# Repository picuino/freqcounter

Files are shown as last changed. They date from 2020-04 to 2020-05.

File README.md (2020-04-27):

Frequency counter
=================
This is a cheap and simple but powerful frequency counter capable 
of measurements of frequency with 8 digits of resolution every second
(9 digits of resolution in 10 second averages).

This frequency counter is based on a little **PIC 16F18446** a 
16x2 LCD display (optional) and USB-Serial interface with PC.

All the programs and hardware designs are free, open source and
open hardware.

The frequency counter have a Command Line Interface via serial 
communications for manage multiple internal options. 
You can read more in [Command Line Interface help](docs/commands.md)

You can mount the frequency counter over a breadboard with this simple 
[schematic](breadboard/kicad/freqcounter_16F18446.pdf)
with a cost of few dollars.
The LDC display is optional. All the info is sended via serial.

Specifications
--------------
* Input frequency range: 0.01 Hz to 15MHz
* Resolution: 8 digits per second (10ns of resolution) at all frequencies.
* Precision: 0.1PPM with simple crystal and calibration.
* Number of inputs: 2 TTL inputs + 1 Zero Cross Detection input
* Output: Frequency or Period, time and pulses counted.
* Phase delay: between 2 inputs with 10ns of resolution.
* Gate times: 1 second and 0.1 seconds.
* Output: via LCD (optional) and serial UART.
* Autocalibration: with 1PPS signal or with 10MHz signal.
* Reciprocal counting: allow calculate lower frequencies with decimals.
* Continuous timestamp: allow frequency averages without error.
* Frequency autorange from Mega Hertz to milli Hertz.
* Adaptable system frequency without reprogramming (8MHz internal or 5MHz external)
* Command Line Interface: via USB-serial communications for configuring options.
* Input levels: between 0.8v (LOW) and 3.1V (HIGH).
* Power Supply: 5 volts.
* DIY: you can mount it with a breadboard and one crystal oscillator.

Images
------
Example of frequency meter conected to an Arduino.
Arduino gives power and serial communications with PC.

Orange cables are the 2 TTL inputs.

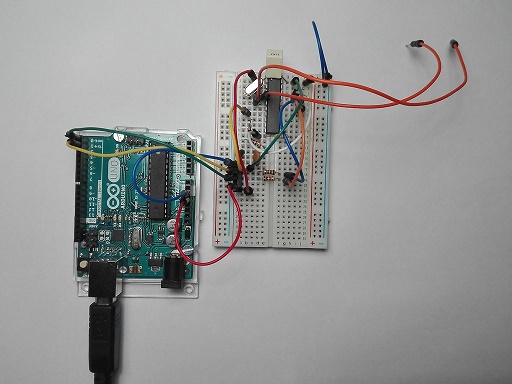
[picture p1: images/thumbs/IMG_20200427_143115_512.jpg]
Frequency meter on breadboard with Arduino


[Full image](images/IMG_20200427_143115.jpg)

Licenses
--------

* Creative Commons Atribution-ShareAlike version 4, for hardware designs,
  texts, photograps, layouts, schematics, and similar.

* GNU General Public License version 3, for microcontroller 
  and computer programs.

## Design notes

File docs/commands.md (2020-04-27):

Frequency counter Command Line Interface
========================================
Brief description of the serial commands that accepts the frequency counter.

The frequency counter communicates with PC via serial.
A USB-Serial converter is needed in order to make serial communications.

The configuration of serial interface is standard:
  * 1 initial start bit
  * 8 data bits
  * 1 stop bit at the end
  * 115200 bauds

Every command line must be terminated with new line character ('\n' or 0x0A).
Other characters like carriage return ('\r' or 0x0D) will be ignored.

Outputs
-------

<dl>

<dt>output time on</dt>
<dd>Enable printing of the duration of the sampling period.</dd>

<dt>output time off</dt>
<dd>Disable printing of the duration of the sampling period.</dd>

<dt>output pulses on</dt>
<dd>Enable printing of counted pulses during the sampling period.</dd>

<dt>output pulses off</dt>
<dd>Disable printing of counted pulses during the sampling period.</dd>

<dt>output longfreq on</dt>
<dd>Enable printing of average frequency of last 10 readings 
    with one digit of resolution added.</dd>

<dt>output longfreq off</dt>
<dd>Disable printing of average frequency.</dd>

<dt>output period on</dt>
<dd>Enable printing of period instead of frequency.</dd>

<dt>output period off</dt>
<dd>Disable printing of frequency instead of period.</dd>

<dt>output phase on</dt>
<dd>Enable printing of time phase between 2 inputs. 
    A minimal phase of 110us is needed between the inputs.</dd>

<dt>output phase off</dt>
<dd>Disable printing of phase between 2 inputs.</dd>

</dl>

Inputs
------

<dl>

<dt>input ch A</dt>
<dd>Activate frequency measure in channel A and switch off channel B.</dd>

<dt>input ch B</dt>
<dd>Activate frequency measure in channel B and switch off channel A.</dd>

<dt>input ch AB</dt>
<dd>Activate frequency measure in both channel A and channel B.</dd>

<dt>input ch</dt>
<dd>Return actual active channels.</dd>

<dt>input ctmu on</dt>
<dd>Enable measurement of frequency with one digit more resolution.
    The measurement is developed with the charge of capacitor 
    (Charge Time Measurement Unit).</dd>

<dt>input ctmu off</dt>
<dd>Disable measurement of frequency with CTMU.</dd>

<dt>input ctmu</dt>
<dd>Return the actual value of ctmu measurement.</dd>

<dt>input fast on</dt>
<dd>Enable fast measurement of frequency (gate time of 0.1 second).</dd>

<dt>input fast off</dt>
<dd>Disable fast measurement of frequency (gate time of 1.0 second).</dd>

<dt>input fast</dt>
<dd>Return the actual value of fast measurement.</dd>

<dt>input zcd on</dt>
<dd>Enable ZCD input instead of Input A.
    The ZCD (Zero Cross Detect) input detects zero crossing of 
    sinusoidal signals like pure audio tones.</dd>

<dt>input zcd off</dt>
<dd>Disable the ZCD input and connect the Input A.</dd>

Calibration
-----------

<dl>

<dt>cal read</dt>
<dd>Read calibration value in PPB (Parts Per Billion).
  Show the calibration value in RAM (value currently used)
  and the calibration value in EPROM (value used after power on).
</dd>

<dt>cal write [number]</dt>
<dd>Writes a new calibration value to calibration variable.</dd>

<dt>cal save</dt>
<dd>Save the actual value of calibration in Flash memory, so this 
  value will be readed after next reset or power on.</dd>

<dt>cal auto on</dt>
<dd>Switch on the autocalibration mode. 
  In this mode the frequency counter changes the calibration value 
  so that the reading is exactly 1Hz or 10MHz.
  
  The frequency counter detects automatically the frequency measured
  and only responds to frequencies near 1Hz or near 10MHz.
  This calibration value in maintained in RAM memory. If you want
  to make this value fixed, use the "cal save" command</dd>

<dt>cal auto off</dt>
<dd>switch off autocalibration mode.</dd>

<dt>cal auto</dt>
<dd>Return the actual value of autocalibration mode.</dd>

</dl>

Reset
-----
<dl>
<dt>reset</dt>
<dd>Reset frequency counter options and counters.</dd>
</dl>

Version
-------
<dl>
<dt>version</dt>
<dd>Shows the version date of the firmware.</dd>
</dl>

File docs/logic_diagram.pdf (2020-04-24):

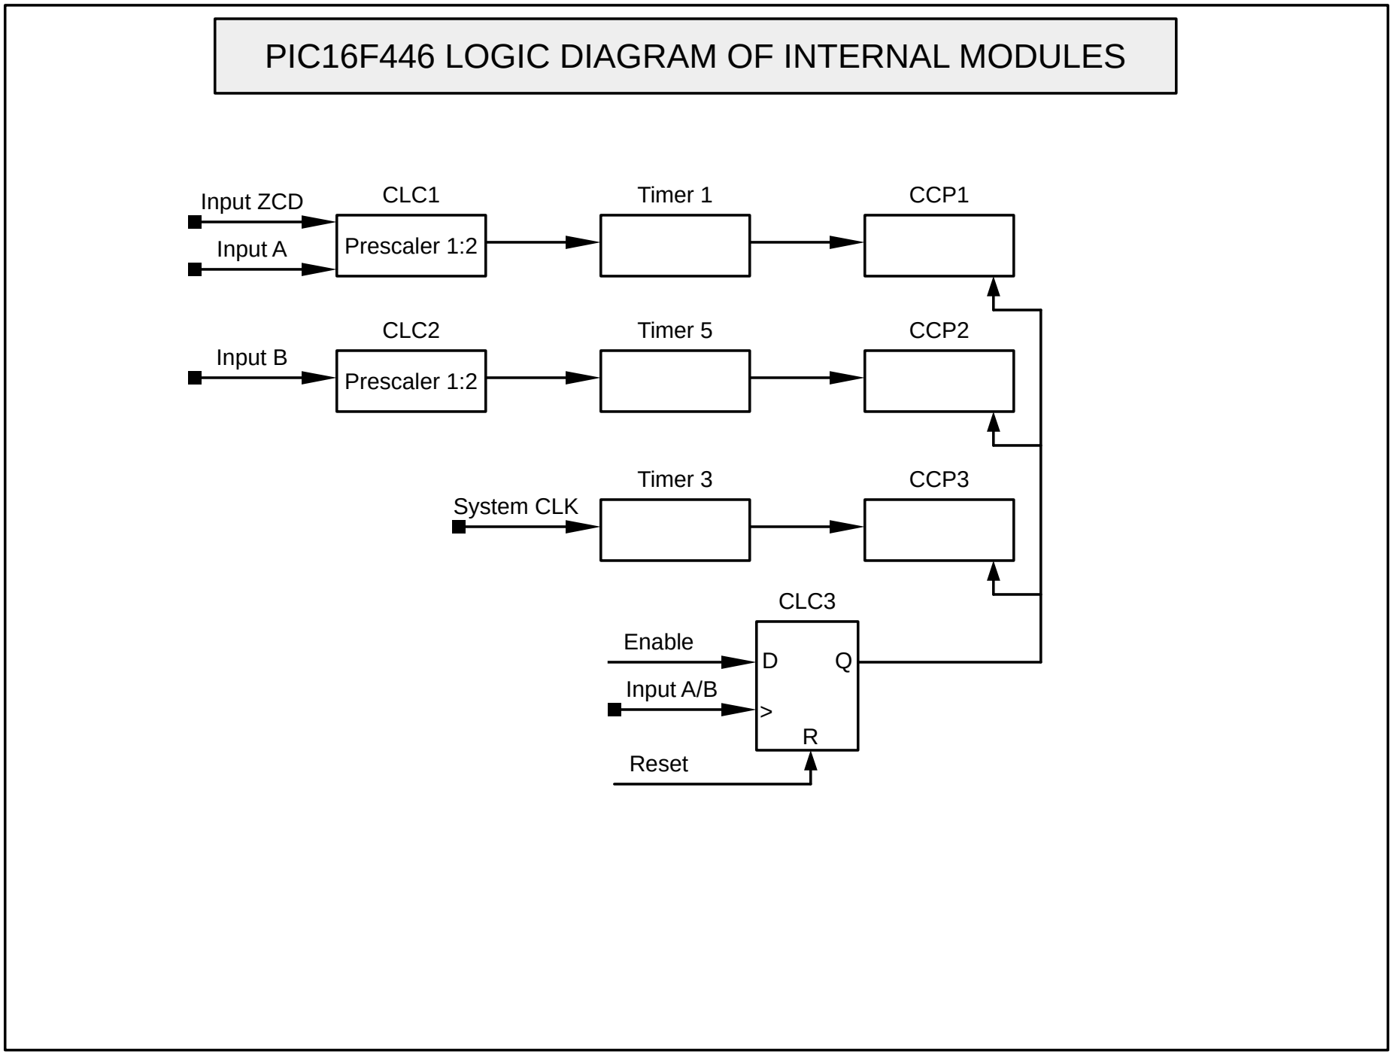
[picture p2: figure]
Prescaler 1:2; CLC1; Input A; Timer 1; CLC2; Input B; Timer 5; System CLK; Timer 3; CCP2; CCP1; CCP3; CLC3; Input A/B; Enable; Reset; Input ZCD

## PIC16F446 LOGIC DIAGRAM OF INTERNAL MODULES

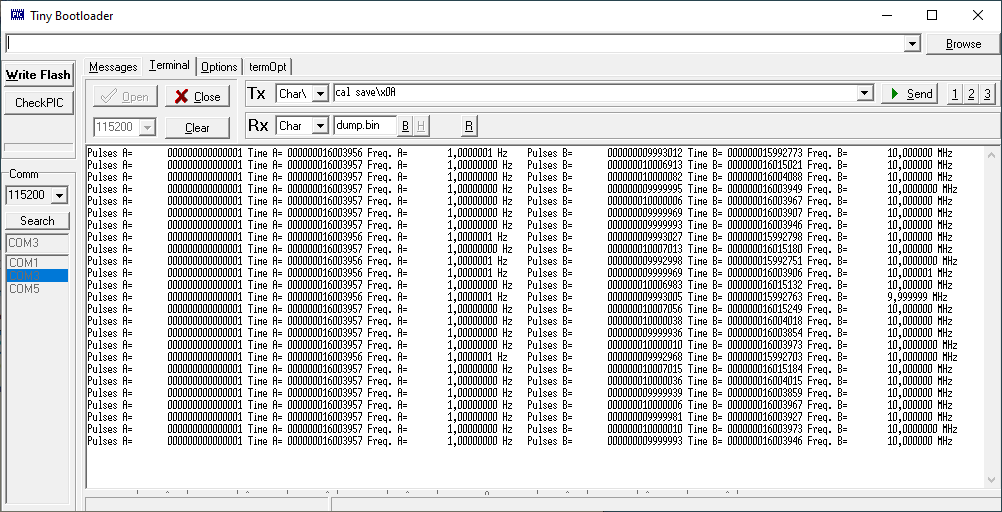
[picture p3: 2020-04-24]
images/two_inputs_GPS_OCXO_0001.png

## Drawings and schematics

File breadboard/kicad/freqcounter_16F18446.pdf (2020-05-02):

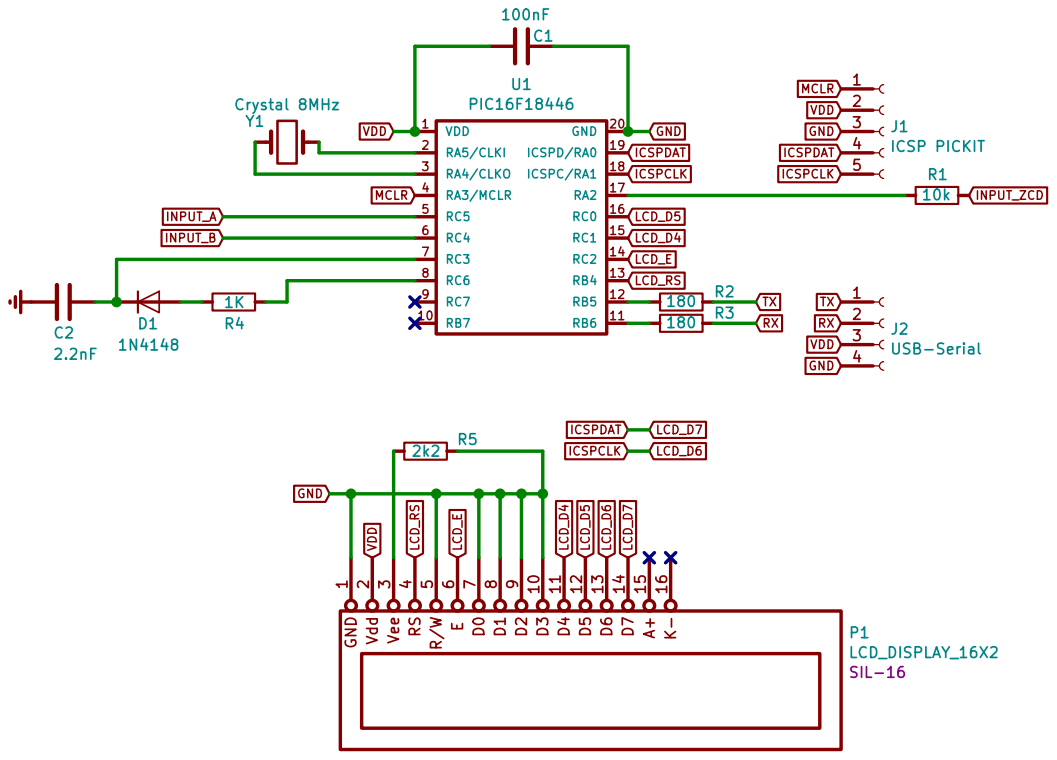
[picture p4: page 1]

License CC BY-SA 4.0
File: freqcounter_16F18446.sch Sheet: / PICUINO

Id: 1/1 Title: FREQUENCY COUNTER WITH PIC16F18446

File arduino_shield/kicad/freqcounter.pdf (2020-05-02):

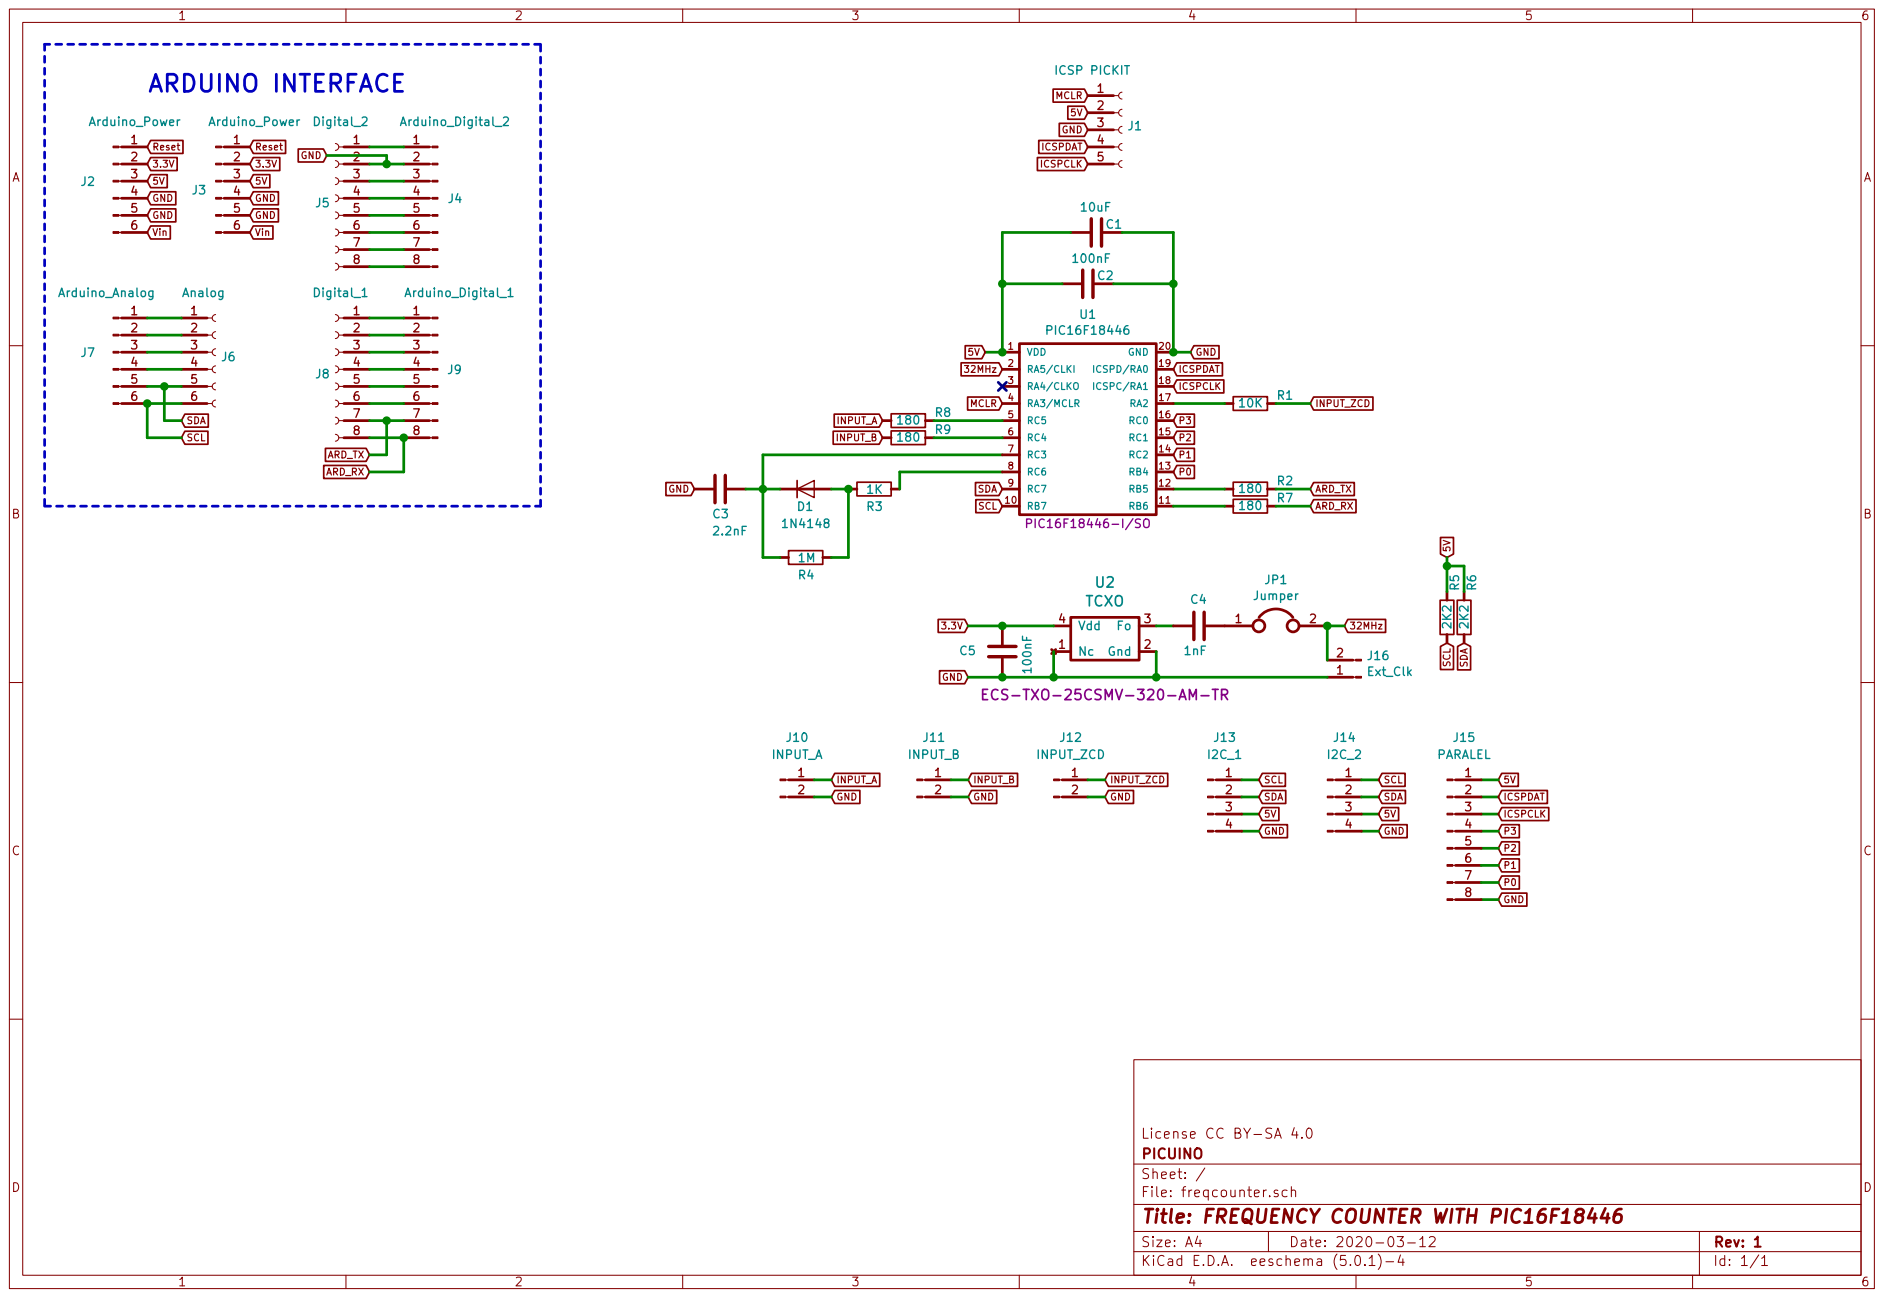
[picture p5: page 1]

ECS-TXO-25CSMV-320-AM-TR

License CC BY-SA 4.0
File: freqcounter.sch Sheet: / PICUINO

Id: 1/1 Title: FREQUENCY COUNTER WITH PIC16F18446

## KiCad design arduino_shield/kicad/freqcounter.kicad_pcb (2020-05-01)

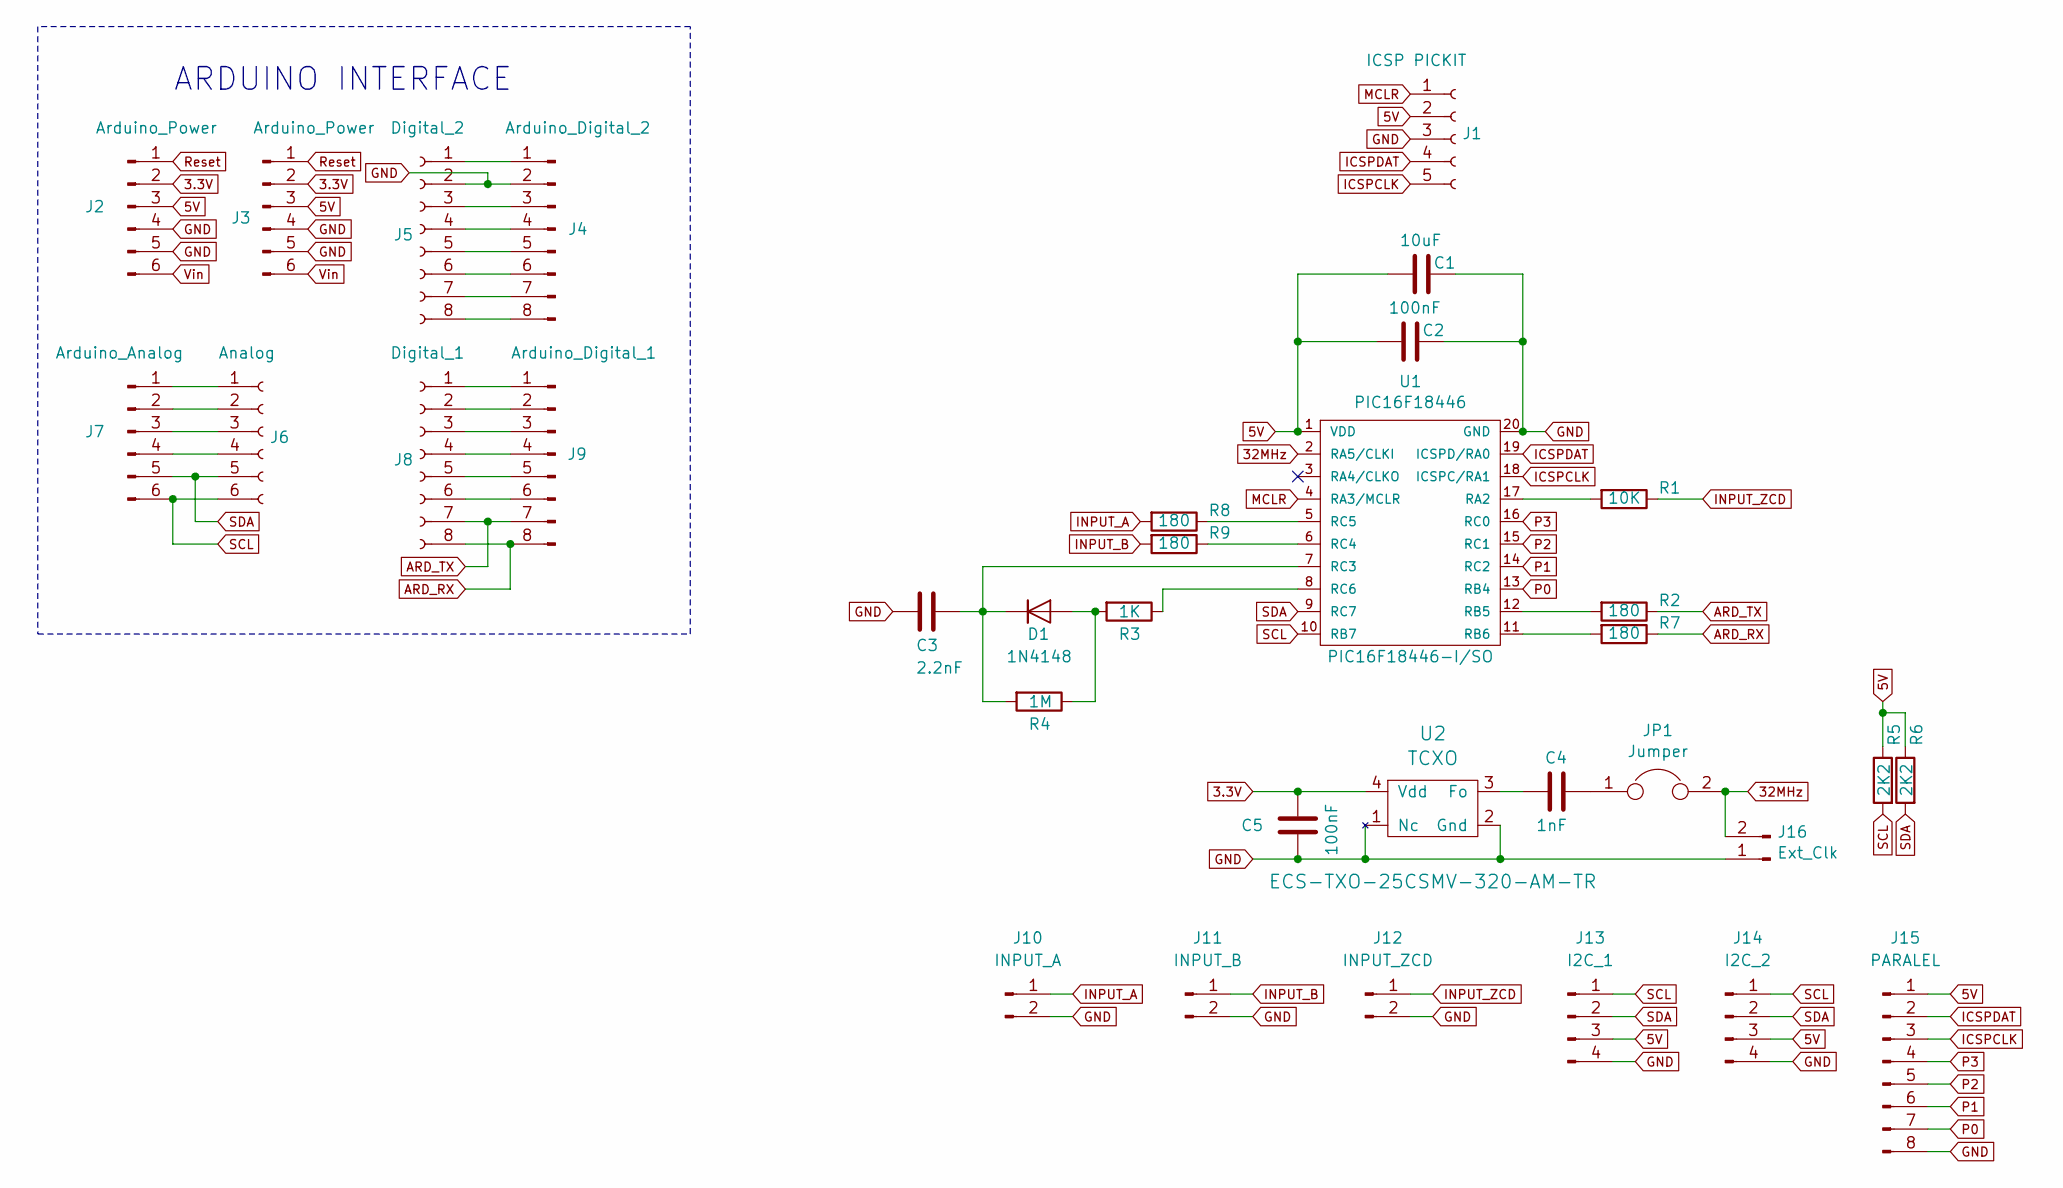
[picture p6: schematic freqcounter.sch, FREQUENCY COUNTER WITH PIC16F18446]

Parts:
C1: 10uF; C_0805_2012Metric_Pad1.15x1.40mm_HandSolder
C2, C5: 100nF; C_0805_2012Metric_Pad1.15x1.40mm_HandSolder
C3: 2.2nF; C_0805_2012Metric_Pad1.15x1.40mm_HandSolder
C4: 1nF; C_0805_2012Metric_Pad1.15x1.40mm_HandSolder
D1: 1N4148; SOD-80_HandSolder
J1: ICSP PICKIT; PinHeader_1x05_P2.54mm_Vertical
J2, J3: Arduino_Power; Connector_1x06
J4: Arduino_Digital_2; Connector_1x08
J5: Digital_2; Connector_1x08
J6: Analog; Connector_1x06
J7: Arduino_Analog; Connector_1x06
J8: Digital_1; Connector_1x08
J9: Arduino_Digital_1; Connector_1x08
J10: INPUT_A; PinHeader_1x02_P2.54mm_Vertical
J11: INPUT_B; PinHeader_1x02_P2.54mm_Vertical
J12: INPUT_ZCD; PinHeader_1x02_P2.54mm_Vertical
J13: I2C_1; PinHeader_1x04_P2.54mm_Vertical
J14: I2C_2; PinHeader_1x04_P2.54mm_Vertical
J15: PARALEL; Connector_1x08
J16: Ext_Clk; PinHeader_1x02
JP1: Jumper; PinHeader_1x02
R1: 10K; R_0805_2012Metric_Pad1.15x1.40mm_HandSolder
R2, R7, R8, R9: 180; R_0805_2012Metric_Pad1.15x1.40mm_HandSolder
R3: 1K; R_0805_2012Metric_Pad1.15x1.40mm_HandSolder
R4: 1M; R_0805_2012Metric_Pad1.15x1.40mm_HandSolder
R5, R6: 2K2; R_0805_2012Metric_Pad1.15x1.40mm_HandSolder
U1: PIC16F18446; SOIC-20W_7.5x12.8mm_P1.27mm
U2: TCXO; TCXO-5032

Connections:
3.3V: C5.2, J2.2, J3.2, U2.4 (Vdd)
5V: C1.2, C2.2, J1.2, J2.3, J3.3, J13.3, J14.3, J15.1, R5.1, R6.1, U1.1 (VDD)
32MHz: J16.2, JP1.2, U1.2 (RA5/CLKI)
ARD_RX: J8.8, J9.8, R7.1
ARD_TX: J8.7, J9.7, R2.1
GND: C1.1, C2.1, C3.2, C5.1, J1.3, J2.4, J2.5, J3.4, J3.5, J4.2, J5.2, J10.2, J11.2, J12.2, J13.4, J14.4, J15.8, J16.1, U1.20 (GND), U2.1 (Nc), U2.2 (Gnd)
ICSPCLK: J1.5, J15.3, U1.18 (ICSPC/RA1)
ICSPDAT: J1.4, J15.2, U1.19 (ICSPD/RA0)
INPUT_A: J10.1, R8.2
INPUT_B: J11.1, R9.2
INPUT_ZCD: J12.1, R1.1
MCLR: J1.1, U1.4 (RA3/MCLR)
unnamed: C3.1, D1.1 (K), R4.2, U1.7 (RC3)
unnamed: C4.1, U2.3 (Fo)
unnamed: C4.2, JP1.1
unnamed: D1.2 (A), R3.2, R4.1
unnamed: J4.1, J5.1
unnamed: J4.3, J5.3
unnamed: J4.4, J5.4
unnamed: J4.5, J5.5
unnamed: J4.6, J5.6
unnamed: J4.7, J5.7
unnamed: J4.8, J5.8
unnamed: J6.1, J7.1
unnamed: J6.2, J7.2
unnamed: J6.3, J7.3
unnamed: J6.4, J7.4
unnamed: J8.1, J9.1
unnamed: J8.2, J9.2
unnamed: J8.3, J9.3
unnamed: J8.4, J9.4
unnamed: J8.5, J9.5
unnamed: J8.6, J9.6
unnamed: R1.2, U1.17 (RA2)
unnamed: R2.2, U1.12 (RB5)
unnamed: R3.1, U1.8 (RC6)
unnamed: R7.2, U1.11 (RB6)
unnamed: R8.1, U1.5 (RC5)
unnamed: R9.1, U1.6 (RC4)
P0: J15.7, U1.13 (RB4)
P1: J15.6, U1.14 (RC2)
P2: J15.5, U1.15 (RC1)
P3: J15.4, U1.16 (RC0)
Reset: J2.1, J3.1
SCL: J6.6, J7.6, J13.1, J14.1, R5.2, U1.10 (RB7)
SDA: J6.5, J7.5, J13.2, J14.2, R6.2, U1.9 (RC7)
Vin: J2.6, J3.6

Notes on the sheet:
ARDUINO INTERFACE

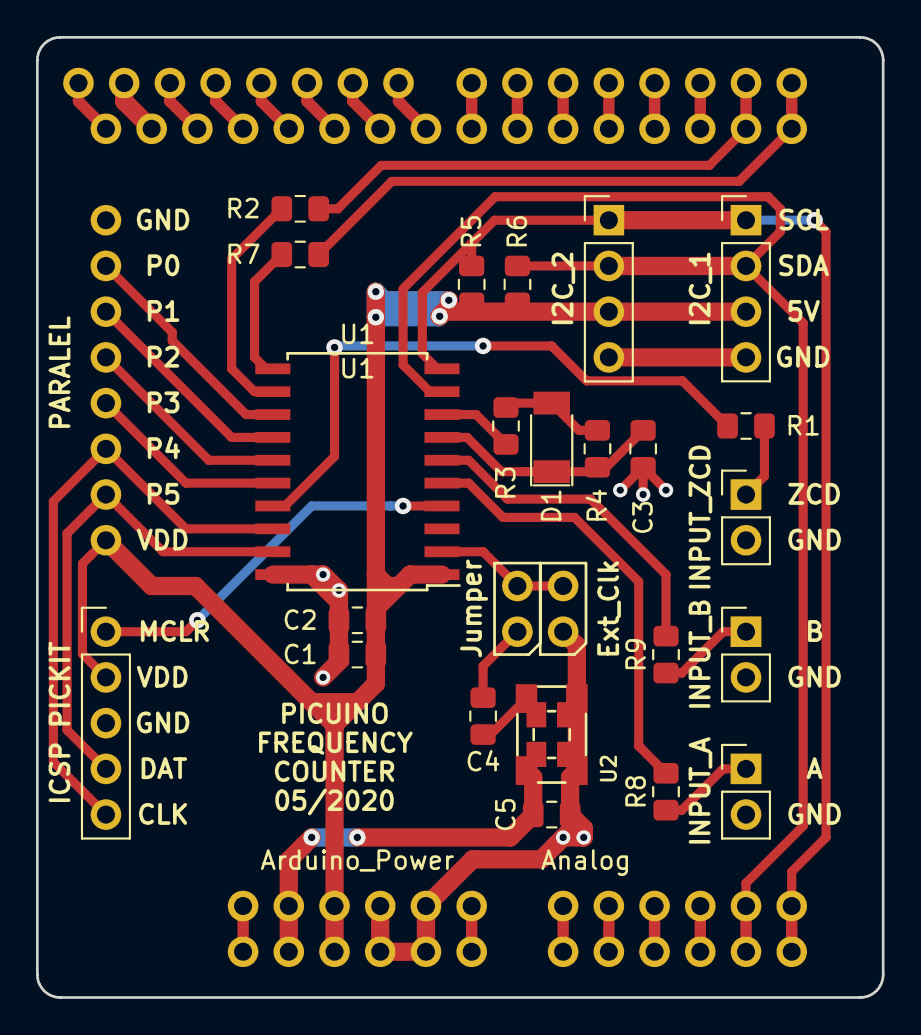
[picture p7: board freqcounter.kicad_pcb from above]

Board: 2 copper layers, 47.0 x 53.3 mm, 34 parts (0 on the bottom side), 47 nets.

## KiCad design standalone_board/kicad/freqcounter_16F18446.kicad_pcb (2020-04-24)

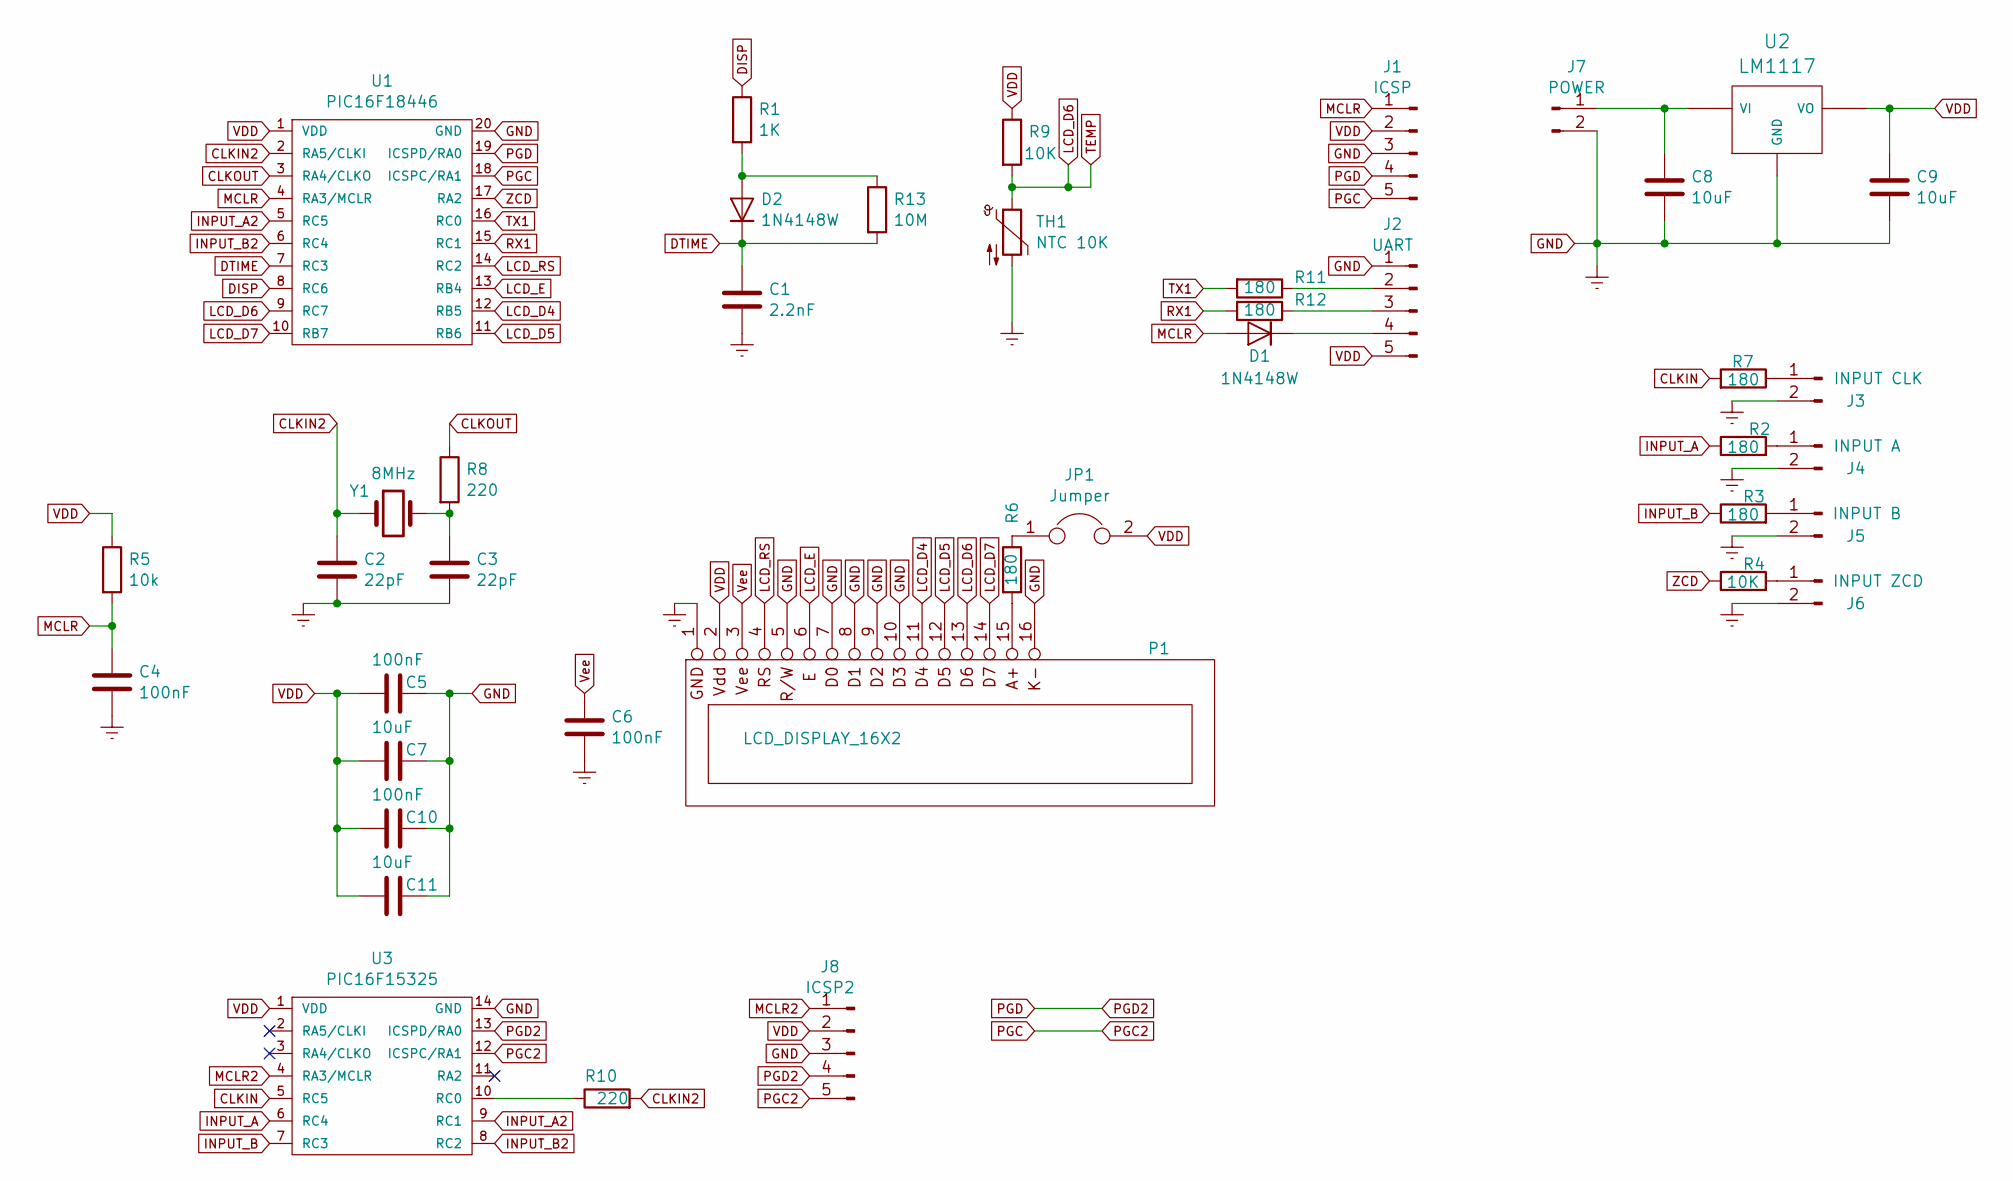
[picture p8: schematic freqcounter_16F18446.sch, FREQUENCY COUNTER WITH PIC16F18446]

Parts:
C1: 2.2nF; C_0805_2012Metric_Pad1.15x1.40mm_HandSolder
C2, C3: 22pF; C_0805_2012Metric_Pad1.15x1.40mm_HandSolder
C4, C5, C6, C10: 100nF; C_0805_2012Metric_Pad1.15x1.40mm_HandSolder
C7, C11: 10uF; C_0805_2012Metric_Pad1.15x1.40mm_HandSolder
C8, C9: 10uF; C_Rect_L4.6mm_W5.5mm_P2.50mm_MKS02_FKP02
D1, D2: 1N4148W; D_SOD-123
J1: ICSP; PinHeader_1x05_P2.54mm_Vertical
J2: UART; PinHeader_1x05_P2.54mm_Vertical
J3: INPUT CLK; PinHeader_1x02_P2.54mm_Vertical
J4: INPUT A; PinHeader_1x02_P2.54mm_Vertical
J5: INPUT B; PinHeader_1x02_P2.54mm_Vertical
J6: INPUT ZCD; PinHeader_1x02_P2.54mm_Vertical
J7: POWER; PinHeader_1x02_P2.54mm_Vertical
J8: ICSP2; PinHeader_1x05_P2.54mm_Vertical
JP1: Jumper; PinHeader_1x02_P2.54mm_Vertical
P1: LCD_DISPLAY_16X2; PinHeader_1x16_P2.54mm_Vertical
R1: 1K; R_0805_2012Metric_Pad1.15x1.40mm_HandSolder
R2, R3, R6, R7, R11, R12: 180; R_0805_2012Metric_Pad1.15x1.40mm_HandSolder
R4, R9: 10K; R_0805_2012Metric_Pad1.15x1.40mm_HandSolder
R5: 10k; R_0805_2012Metric_Pad1.15x1.40mm_HandSolder
R8, R10: 220; R_0805_2012Metric_Pad1.15x1.40mm_HandSolder
R13: 10M; R_0805_2012Metric_Pad1.15x1.40mm_HandSolder
TH1: NTC 10K; R_0805_2012Metric_Pad1.15x1.40mm_HandSolder
U1: PIC16F18446; SOIC-20W_7.5x12.8mm_P1.27mm
U2: LM1117; SOT223_LM1117
U3: PIC16F15325
Y1: 8MHz; Crystal_HC18-U_Vertical

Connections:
CLKIN: R7.2, U3.5 (RC5)
CLKIN2: C2.1, R10.2, U1.2 (RA5/CLKI), Y1.1
CLKOUT: R8.1, U1.3 (RA4/CLKO)
DISP: R1.1, U1.8 (RC6)
DTIME: C1.1, D2.1 (K), R13.2, U1.7 (RC3)
GND: C1.2, C2.2, C3.2, C4.2, C5.1, C6.2, C7.1, C8.2, C9.2, C10.1, C11.1, J1.3, J2.1, J3.2, J4.2, J5.2, J6.2, J7.2, J8.3, P1.1, P1.5, P1.7, P1.8, P1.9, P1.10, P1.16, TH1.2, U1.20 (GND), U2.GND, U3.14 (GND)
INPUT_A: R2.1, U3.6 (RC4)
INPUT_A2: U1.5 (RC5), U3.9 (RC1)
INPUT_B: R3.1, U3.7 (RC3)
INPUT_B2: U1.6 (RC4), U3.8 (RC2)
LCD_D4: P1.11, U1.12 (RB5)
LCD_D5: P1.12, U1.11 (RB6)
LCD_D6: P1.13, R9.2, TH1.1, U1.9 (RC7)
LCD_D7: P1.14, U1.10 (RB7)
LCD_E: P1.6, U1.13 (RB4)
LCD_RS: P1.4, U1.14 (RC2)
MCLR: C4.1, D1.2 (A), J1.1, R5.2, U1.4 (RA3/MCLR)
MCLR2: J8.1, U3.4 (RA3/MCLR)
unnamed: C3.1, R8.2, Y1.2
unnamed: C8.1, J7.1, U2.VI
unnamed: D1.1 (K), J2.4
unnamed: D2.2 (A), R1.2, R13.1
unnamed: J2.2, R11.1
unnamed: J2.3, R12.1
unnamed: J3.1, R7.1
unnamed: J4.1, R2.2
unnamed: J5.1, R3.2
unnamed: J6.1, R4.2
unnamed: JP1.1, R6.1
unnamed: P1.15, R6.2
unnamed: R10.1, U3.10 (RC0)
PGC: J1.5, J8.5, U1.18 (ICSPC/RA1), U3.12 (ICSPC/RA1)
PGD: J1.4, J8.4, U1.19 (ICSPD/RA0), U3.13 (ICSPD/RA0)
RX1: R12.2, U1.15 (RC1)
TX1: R11.2, U1.16 (RC0)
VDD: C5.2, C7.2, C9.1, C10.2, C11.2, J1.2, J2.5, J8.2, JP1.2, P1.2, R5.1, R9.1, U1.1 (VDD), U2.VO, U3.1 (VDD)
Vee: C6.1, P1.3
ZCD: R4.1, U1.17 (RA2)

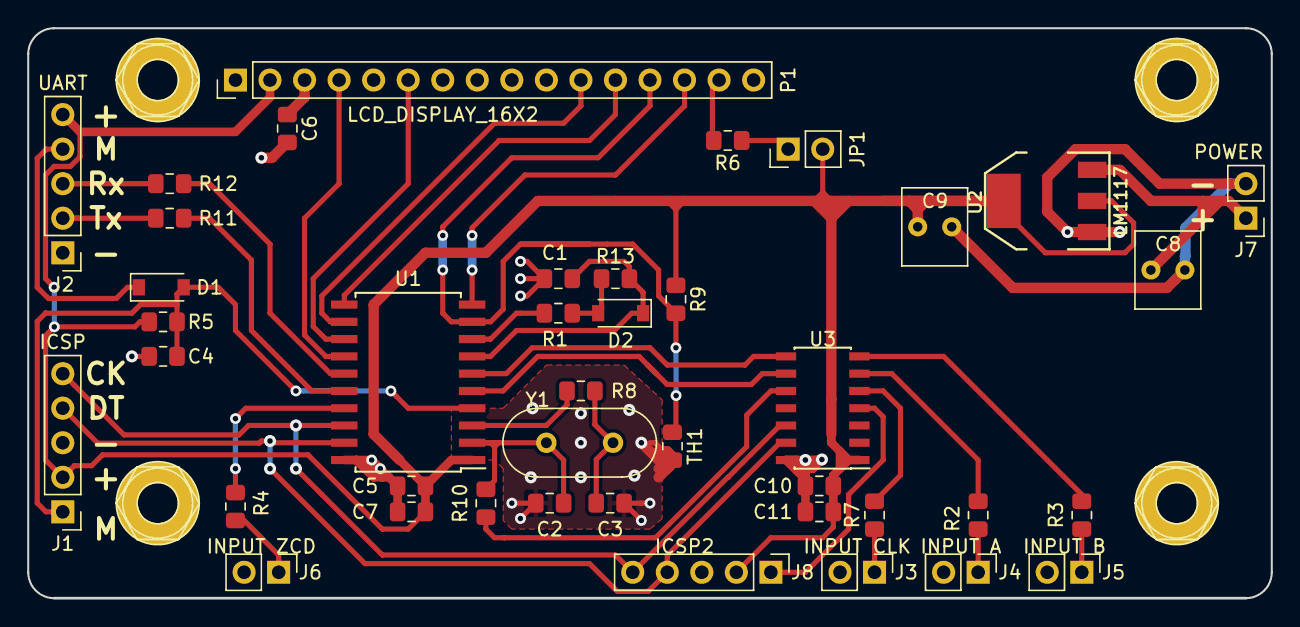
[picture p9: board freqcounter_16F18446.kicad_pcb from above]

Board: 2 copper layers, 91.4 x 41.9 mm, 45 parts (0 on the bottom side), 38 nets.

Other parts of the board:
M3, M3#2, M3#3, M3#4: SCREW_M3

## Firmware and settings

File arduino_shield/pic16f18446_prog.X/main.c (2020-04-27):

/*
 * Frequency counter with PIC16F18446
 *
 * Author: Carlos Pardo
 *
 * Inputs:
 *    RC5 (Pin_5) Input A
 *    RC4 (Pin_6) Input B
 *
 * UART:
 *   TX on RA2 (Pin_17)
 *   RX on RC0 (Pin_16)
 *
 *
 * TO-DO:
 *  - Refactor and clean code
 *
 * License:
 *
 * This file is subject to the terms and conditions of the GNU General
 * Public License Version 3. See the file "COPYING" in the main directory
 * of this archive for more details.
 *
 */

#include <xc.h>
#include "config.h"
#include "peripheral.h"
#include "timers.h"
#include "math48.h"
#include "uart.h"
#include "counter.h"
#include "lcd.h"
#include "eprom.h"
#include "command.h"
#include "calibration.h"

extern options_t options;


/*
 *  INTERRUPT SERVICE ROUTINE
 */
void __interrupt() isr(void) {

   // Interrupt service routine of timers
   timers_isr();

   // Interrupt service routine of UART
   uart_isr();
}


/*
 *  Inits CPU
 */
void cpu_init(void) {
   // Disable interrupts
   INTCON = 0;

   // Oscillator
   WDTCON0bits.SWDTEN = 0; // Watchdog disabled

   // Init ports
   ANSELA = 0;
   ANSELB = 0;
   ANSELC = 0;
   LATA = 0x00;
   LATB = 0x00;
   LATC = 0x00;
   TRISA = 0xFF;
   TRISB = 0xFF;
   TRISC = 0xFF;

   // Weak pull up resistors
   WPUA = 0;
   WPUB = 0;
   WPUC = 0;
   WPUAbits.WPUA3 = 1; // MCLR wpu

   // Enable interrupts
   INTCONbits.PEIE = 1;
   INTCONbits.GIE = 0;
}

/*
 *  MAIN FUNCTION
 */
void main(void) {
   extern char counter_reset_inputs;

   // Configure System clock frequency
   options.system_clk_mhz = 8;

   // Init CPU and peripherals
   cpu_init();
   pps_init();
   uart_init();
   timer0_init();
   lcd_init();
   adc_init();
   clc_init();
   zcd_init();

   // Enable interrupts and send wellcome message
   INTCONbits.GIE = 1;
   counter_wait_period();
   cmd_version();
   lcd_puts("System OK");


   // Init modules
   cmd_init();
   calibrate_init();
   counter_init();

   // Frequency counter main loop
   while (1) {
      counter_prescaler_channel_a();
      counter_prescaler_channel_b();

      counter_wait_period();
      system_speed();

      if (counter_reset_inputs == 1) {
         counter_reset_inputs = 0;
         uart_fputs("# Reset counters\n");
         counter_reset();
         continue;
      }

      counter_save_old_values();
      ctmu_calibrate();
      counter_capture_channels();

      counter_print_channel_a();
      counter_print_channel_b();
      counter_print_end();

      // Autocalibrate with the last signal measured
      counter_1pps_autocalibrate();
      counter_10mhz_autocalibrate();
   }
}

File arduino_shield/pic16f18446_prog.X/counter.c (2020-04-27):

/*
 * Frequency counter routines
 *
 * Author: Carlos Pardo
 *
 * This file is subject to the terms and conditions of the GNU General
 * Public License Version 3. See the file "COPYING" in the main directory
 * of this archive for more details.
 *
 */

#include <xc.h>
#include "config.h"
#include "peripheral.h"
#include "timers.h"
#include "math48.h"
#include "uart.h"
#include "lcd.h"
#include "eprom.h"
#include "command.h"
#include "counter.h"
#include "calibration.h"


/*
 * GLOBAL VARIABLES
 */
extern volatile uint48 timer0, timer1, timer3, timer5;
extern volatile unsigned char timers_readed;
extern unsigned char str_buf[];
extern unsigned int ctmu_constant;
extern calibration_t calibration;

uint48 buff_pulses_a[COUNTER_BUFFER_SIZE];
uint48 buff_time_a[COUNTER_BUFFER_SIZE];
uint48 buff_pulses_b[COUNTER_BUFFER_SIZE];
uint48 buff_time_b[COUNTER_BUFFER_SIZE];
uint48 frequency, period;
uint48 temp, time;
uint48 pulses_a, time_a;
uint48 pulses_b, time_b;
uint48 pulses_a_old, time_a_old;
uint48 pulses_b_old, time_b_old;
uint48 dpulses, dtime, dpulsesf, dtimef;
char buff_init, buff_end;
options_t options;
unsigned int ctmu, ctmu_a, ctmu_b;
unsigned long millis;
unsigned char blink_lcd_state;
unsigned char counter_reset_inputs;
unsigned char counter_capturing_channel;
unsigned char counter_overrange_input_a, counter_overrange_input_b;


/*
 * Calculate frequency
 * input: dpulses and dtime as uint48 integer numbers
 *        options.calibration as long integer.
 * output: frequency as float48 float number
 */
void counter_calculate_frequency(void) {

   // Calculate pulses in floating point format
   dpulsesf = itof48(dpulses);

   // Calculate time in floating point format and change units to seconds
   if (options.ctmu_enable) {
      if (options.system_clk_mhz == 8) {
         ILOAD48(temp, 128 * _FCYCLES);
      } else {
         ILOAD48(temp, 128 * 5000000);
      }
   } else {
      if (options.system_clk_mhz == 8) {
         ILOAD48(temp, _FCYCLES);
      } else {
         ILOAD48(temp, 5000000);
      }
   }

   temp = itof48(temp);
   dtimef = itof48(dtime);
   dtimef = fdiv48(dtimef, temp);
   dtimef = fdiv48(dtimef, calibration_get());

   // Calculate frequency
   frequency = dpulsesf;
   frequency = fdiv48(frequency, dtimef);

   // Calculate period if pulses > 0
   if (dpulses.word[0] > 0 || dpulses.dword > 0) {
      ILOAD48(temp, 1UL);
      temp = itof48(temp);
      period = fdiv48(temp, frequency);
   }
}


/*
 * Calculate period of input A
 * Input:
 *    pulses_a, pulses_a_old,
 *    time_a, time_a_old
 *
 * Output:
 *    dpulses (difference of pulses in period)
 *    dtime   (difference of time in period in cycle units)
 */
void counter_period_a(void) {
   // calculate differencies
   dpulses = sub48(pulses_a, pulses_a_old);
   counter_unprescaler(options.prescaler_a);

   // Calculate time in cycles
   dtime = sub48(time_a, time_a_old);
}


/*
 * Calculate period of input B
 * Input:
 *    pulses_b, pulses_b_old,
 *    time_b, time_b_old
 *
 * Output:
 *    dpulses (difference of pulses in period)
 *    dtime   (difference of time in period in cycle units)
 */
void counter_period_b(void) {
   // calculate differencies
   dpulses = sub48(pulses_b, pulses_b_old);
   counter_unprescaler(options.prescaler_b);

   // Calculate time in cycles
   dtime = sub48(time_b, time_b_old);
}


/*
 * Capture pulses and time
 * Read CTMU for more precise time measure
 */
void counter_capture(void) {
   // discharge ctmu capacitor
   ctmu_discharge();

   // Inits capture
   timers_readed = 0;
   CLC3_RESET = 0;
   CLC3_DATA = 1;

   // Read timer1
   while (timers_readed == 0)
      cmd_loop();

   // Reset capture
   CLC3_RESET = 1;
   CLC3_DATA = 0;

   // Read CTMU capacitor with ADC
   if (options.ctmu_enable)
      ctmu = adc_read();
}


/*
 * wait one measuring period since the last wait.
 */
void counter_wait_period(void) {
   // Wait one measuring period
   if (options.fast_measure) {
      millis += 100;
      if ((long) (millis - milliseconds()) < 0)
         millis = milliseconds() + 50;
   } else {
      millis += 1000;
      if ((long) (millis - milliseconds()) < 0)
         millis = milliseconds() + 950;
   }
   while ((long) (millis - milliseconds()) > 0)
      cmd_loop();
}


/*
 * Reset options
 */
void counter_options_init(void) {
   options.autocalibrate = 0;
   options.ctmu_enable = 1;
   options.input_a = 1;
   options.input_b = 0;
   options.input_zcd = 0;
   options.fast_measure = 0;

   options.print_pulses = 0;
   options.print_time = 0;
   options.print_long_frequency = 0;
   options.print_period = 0;
   options.print_phase = 0;
   options.print_lcd = 1;

   // Read calibration (in Parts Per Billion)
   calibration.calibration_8mhz = eprom_read32(SAF_ADDRESS);
   calibration.calibration_5mhz = eprom_read32(SAF_ADDRESS + 4);
}


/*
 * Inits frequency counter
 */
void counter_init(void) {
   // Inits capture modules
   ccp1_init();
   ccp3_init();
   ccp2_init();

   // Reset options
   counter_options_init();
   clc_init(); // conect Input A or Input ZCD (Must be executed before reset counters)

   counter_reset();
}


/*
 * Reset timers, buffer and time counter
 */
void counter_reset(void) {
   // Reset timers
   timer1_init();
   timer3_init();
   timer5_init();

   // Wait for Input A pulse and capture
   ctmu_calibrate();
   counter_capture_channels();

   // Inits buffer
   buff_init = 0;
   buff_end = 0;
   buff_pulses_a[0] = pulses_a;
   buff_pulses_b[0] = pulses_b;
   buff_time_a[0] = time_a;
   buff_time_b[0] = time_b;

   // Inits time counter between samples
   millis = milliseconds();
}


void counter_unprescaler(char prescaler) {
   // Change pulses depending on prescaler
   if (prescaler >= 2) {
      dpulses = sl48(dpulses);
   }
   if (prescaler >= 4) {
      dpulses = sl48(dpulses);
   }
   if (prescaler == 8) {
      dpulses = sl48(dpulses);
   }
}


/*
 * Determine prescaler and detects overrange on Input A
 */
void counter_prescaler_channel_a(void) {
   char intcon;

   // Configure Timer2
   T2CON = 0;
   T2HLT = 0;
   T2PR = 0xFF;
   T2CLKCON = 0; // 0 = T2CKIPPS
   T2CONbits.CKPS = 5; // 0 = 1:32 prescaler

   // Measure frequency overrange in channel A
   pps_unlock();
   T2INPPS = INPUT_A_PPS;
   pps_lock();
   T2TMR = 0;

   intcon = INTCON;
   INTCONbits.GIE = 0;
   T2CONbits.ON = 1;
   __delay_us(100);
   T2CONbits.ON = 0;
   INTCON = intcon;

   // Select prescaler
   if (T2TMR < 2 && options.prescaler_a == 2) {
      clc_prescaler_a_off();
      uart_fputs("# Prescaler A=\t1\n");
      counter_reset();
   }
   if (T2TMR > 10 && options.prescaler_a == 1) {
      clc_prescaler_a_on();
      uart_fputs("# Prescaler A=\t2\n");
      counter_reset();
   }

   // Detects overrange
   if (T2TMR >= 48) {
      counter_overrange_input_a = 1;
      uart_fputs("# Over range at input A\n");
   } else {
      counter_overrange_input_a = 0;
   }
}
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

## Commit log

2020-04-25 Move files and directories
    [Freqmeter_16F18446-B.Cu.gbr, Freqmeter_16F18446-B.Mask.gbr, Freqmeter_16F18446-B.SilkS.gbr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]
2020-04-25 Move files and bugfix program project.
    [calibration.c, command.c, counter.c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]
2020-04-25 Updated kicad schematic
    [freqcounter.kicad_pcb, freqcounter.sch, freqcounter_16F18446.sch]
2020-04-27 Images of frequency counter on a breadboard with Arduino.
2020-04-28 Updated Arduino shield schematic and PCB
    [freqcounter.kicad_pcb, freqcounter.sch]
2020-04-28 Updated Schematic and PCB
    [freqcounter.sch]
2020-04-28 Bugfix schematic and PCB
    [freqcounter_16F18446.sch]
2020-04-30 Arduino Shield PCB designed
    [freqcounter-B.Cu.gbr, freqcounter-B.Mask.gbr, freqcounter-B.Paste.gbr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]
2020-04-30 Bugfix Arduino-Shield PCB
    [freqcounter-B.Cu.gbr, freqcounter-B.Mask.gbr, freqcounter-B.Paste.gbr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]
2020-04-30 Bugfix Arduino-Shield Schematic and PCB
    [freqcounter-B.Cu.gbr, freqcounter-B.Mask.gbr, freqcounter-B.Paste.gbr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]
2020-05-01 Updated Arduino-Shield Schematic and PCB
    [freqcounter-B.Cu.gbr, freqcounter-B.Mask.gbr, freqcounter-B.Paste.gbr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]
2020-05-02 Updated schematic
2020-05-02 Added program to Arduino-shield
2020-05-02 Added program for disconecting TX pin and use Arduino as USB-Serial interface
2020-05-02 Updated project. Changed UART and LCD pins
    [freqcounter_16F18446.sch]
